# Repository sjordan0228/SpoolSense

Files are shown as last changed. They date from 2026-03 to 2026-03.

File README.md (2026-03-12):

# Voron NFC Spoolman Integration

Automatic filament spool tracking for Voron printers using NFC tags, ESP32-S3, and Spoolman. Built for multi-toolhead setups, works just as well with a single toolhead.


> 🚀 **Big things coming — AFC, OpenPrintTag, and OpenTag3D support**
> SpoolSense is being restructured to support multiple ecosystems. [AFC/Box Turtle](https://github.com/ArmoredTurtle/AFC-Klipper-Add-On) support is actively being built out, with [OpenPrintTag](https://github.com/OpenPrintTag) and [OpenTag3D](https://github.com/OpenTag3D) integrations planned to follow. During this restructuring, some paths and links may temporarily break — if something looks off, check the [CHANGELOG](CHANGELOG.md) or open an issue.

> 🚧 **Work in Progress**
> This project is a work in progress — honestly more of a guide than a finished product. Yes, there's custom code here, but the main idea is to leverage as much open-source software and tooling as possible to build a working system. Check back often because there's a lot planned. Ideas and contributions are very welcome — open an issue or submit a PR!

> 🙋 **Help Wanted**
> - **Case Design** — I'm currently using a basic printed case and would love help designing something slicker. Ideally something that styles well with popular filament dryers — I'm running the Creality Space Pi X4, but open to designs that work across different dryers. If you're a CAD person, let's collaborate!
> - **Testers & Feedback** — If you build this or any variation of it, please open an issue and let me know how it went. Hardware differences, edge cases, things that didn't work — all of it is valuable.

> 🎯 **Stretch Goal — Bondtech INDX Support**
> A top priority stretch goal is to extend this project to support the [Bondtech INDX](https://www.bondtech.se/indx-by-bondtech/) system as soon as it's publicly available. INDX on a Klipper-based printer is a natural fit for this project — the architecture is already there. If you're from the Bondtech team and want to collaborate, feel free to open an issue or reach out via GitHub.

## Overview

Scan an NFC tag on a filament spool → automatically sets the active spool in Spoolman → updates Spoolman per toolhead → Klipper tracks filament usage → LED on each toolhead confirms the scan and displays the spool color.

```
Scan NFC tag
     ↓
ESP32-S3 + PN532 reads UID
     ↓
ESPHome publishes to MQTT
     ↓
Python middleware on Pi
     ↓
Spoolman lookup by UID
     ↓
Moonraker sets active spool
     ↓
Mainsail/Fluidd shows spool per toolhead
     ↓
LED flashes white 3x (scan confirmed) → holds spool color
```

## Features

Tap an NFC tag on your spool and walk away. That's really it — everything else happens automatically.

**Scan to track** — each toolhead has its own ESP32-S3 constantly listening for NFC tags. The moment you tap a spool, it's registered as active in Spoolman, Moonraker is updated, and your front end reflects it per toolhead. No typing spool IDs, no dropdown menus, no forgetting to update it.

**LED feedback that actually tells you something** — the onboard RGB LED isn't just an "it worked" light. It flashes the filament's exact color from Spoolman so you can glance at the toolhead and know what's loaded. Scan an unknown tag and it goes red. Running low (under 100g)? The LED starts breathing in the filament color so it catches your eye without being obnoxious.

**Survives reboots** — spool IDs are saved to disk via Klipper's save_variables system and restored automatically on startup. Pull the power, come back the next day, and everything is still assigned correctly.

**Scales from single to as many toolheads as you need** — originally built for multi-toolhead setups like MadMax, StealthChanger, and other Voron toolchanger systems, but there's nothing stopping you from running a single reader on a standard setup. Each toolhead is completely independent with its own reader and ESP32, but they all feed into the same Spoolman instance. Configure the `TOOLHEADS` list in the middleware to match your setup — `["T0"]` for single, or as many as you're running. Both Fluidd and Mainsail support per-toolhead spool status natively via `variable_spool_id` in the toolchange macros (Mainsail added this in July 2024).

**Single or toolchanger mode** — set `TOOLHEAD_MODE` in the middleware config to match your printer. Single mode calls `SET_ACTIVE_SPOOL` directly on every scan. Toolchanger mode stores the spool ID per toolhead and lets klipper-toolchanger handle activation automatically at each toolchange — tested and confirmed working on MadMax T0–T3.

**Printable case included** — a custom case is in the `3mf/` folder designed specifically for the Waveshare ESP32-S3-Zero + PN532. Print it clear so the LED glows through. Print the scan target in red so you know where to tap.

## LED Status Indicator
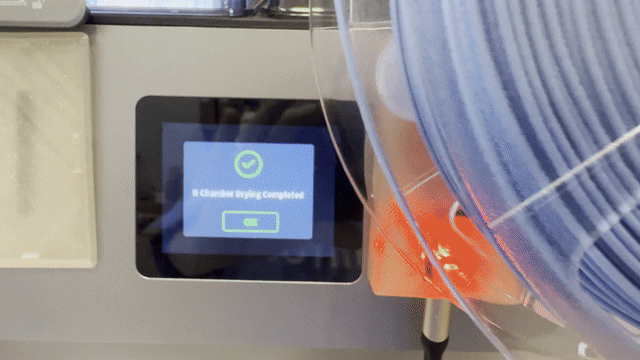
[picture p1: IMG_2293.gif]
LED Status Demo


Each toolhead's onboard WS2812 RGB LED provides visual feedback. This project is tested with the **Waveshare ESP32-S3-Zero**, which includes an onboard WS2812 LED on GPIO21 — no additional wiring required for the LED.

- **3x white flash** — NFC tag successfully scanned
- **Solid spool color** — displays the filament color pulled from Spoolman after a successful scan
- **3x red flash** — tag scanned but not found in Spoolman (unknown or unregistered tag)
- **Breathing in spool color** — spool is running low (at or below `LOW_SPOOL_THRESHOLD`, default 100g)

The LED color is published via MQTT and driven by the middleware using the `color_hex` value stored in Spoolman for each spool.

## Hardware

- 4x [Waveshare ESP32-S3-Zero](https://www.waveshare.com/esp32-s3-zero.htm) *(tested and recommended — onboard WS2812 LED on GPIO21)*
- 4x PN532 NFC Module (I2C mode)
- 4x WS2812 RGB LED (onboard on Waveshare ESP32-S3-Zero, GPIO21)
- Raspberry Pi (Klipper host)
- NFC tags (one per spool)

## Software Stack

- [ESPHome](https://esphome.io) — firmware for ESP32-S3
- [Mosquitto MQTT](https://mosquitto.org) — via Home Assistant addon
- [Spoolman](https://github.com/Donkie/Spoolman) — filament database
- [Moonraker](https://moonraker.readthedocs.io) — Klipper API
- [Fluidd](https://fluidd.xyz) or [Mainsail](https://docs.mainsail.xyz) — both support per-toolhead spool display via `variable_spool_id` in toolchange macros.

## Prerequisites

- Home Assistant with ESPHome and Mosquitto addons
- Klipper + Moonraker running on Raspberry Pi
- Spoolman installed and running
- Fluidd or Mainsail installed

## 3D Printed Case

A custom case is included in the `3mf/` directory, modified from [this model on MakerWorld](https://makerworld.com/en/models/2108947-esp32-c3-pn532-nfc-reader-case-usb-c#profileId-2552448).

Modifications made:
- **Toolhead labels** — T0, T1, T2, T3 text added to each case
- **ESP32-S3-Zero fit** — modified bay designed specifically for the Waveshare ESP32-S3-Zero (get the version without pins and solder wires directly)
- **Scan target** — added a scan target area on the case, suggested to print in red filament

**Printing tips:**
- Print the case itself in a **clear material** (PLA, PETG, or PC) to let the onboard LED shine through for full visual effect
- Print the scan target insert in red for easy identification

## Directory Structure

```
├── esphome/          # ESPHome YAML configs for each toolhead
├── middleware/       # Python MQTT listener script
├── klipper/          # Klipper macro configs
├── 3mf/              # 3D printable case files
├── docs/             # Setup guides
├── scripts/          # Install script (beta)
└── beta/             # Beta features and design docs
```

## Quick Start

**Option A — Interactive install script (beta):**
```bash
git clone https://github.com/sjordan0228/SpoolSense.git
cd SpoolSense
bash scripts/install-beta.sh
```
The script walks you through configuration, installs dependencies, sets up the systemd service, and generates ESPHome YAML files for each scanner.

**Option B — Manual setup:**
1. Wire the PN532 to each ESP32-S3 (see docs/wiring.md)
2. Flash ESPHome configs (see docs/esphome-setup.md)
3. Deploy middleware script (see docs/middleware-setup.md)
4. Add Klipper macros (see docs/klipper-setup.md)
5. Configure Spoolman extra fields (see docs/spoolman-setup.md)

## Automatic Updates via Moonraker

You can add this project to Moonraker's `update_manager` so it appears alongside Klipper, Moonraker, and your other components in Fluidd/Mainsail's update panel. When an update is available, click update and Moonraker will pull the latest code and restart the middleware service automatically.

Add the following to your `moonraker.conf`:

```ini
[update_manager spoolsense]
type: git_repo
path: ~/SpoolSense
origin: https://github.com/sjordan0228/SpoolSense.git
primary_branch: master
managed_services: spoolsense
```

Then clone the repo to your home directory if you haven't already:

```bash
cd ~
git clone https://github.com/sjordan0228/SpoolSense.git
```

Restart Moonraker to pick up the new config:

```bash
sudo systemctl restart moonraker
```

The project should now appear in your update manager panel. Your configuration in `~/SpoolSense/config.yaml` is separate from the repo and will never be overwritten by updates.

## License

GPL-3.0

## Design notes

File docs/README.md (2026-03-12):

# SpoolSense Documentation

> ⚠️ **AFC/BoxTurtle users:** The AFC integration is partially functional — spool scanning and `SET_SPOOL_ID` work today, but LED lane color override depends on [AFC-Klipper-Add-On PR #671](https://github.com/ArmoredTurtle/AFC-Klipper-Add-On/pull/671) being merged before it is fully operational. See [integrations/afc/docs/setup.md](../integrations/afc/docs/setup.md) for the full AFC setup guide.

---

## Toolchanger / Single Toolhead

These guides cover the standard SpoolSense setup — one ESP32-S3-Zero + PN532 per toolhead, or one for a single toolhead printer.

| Guide | What it covers |
|---|---|
| [wiring.md](wiring.md) | PN532 wiring to ESP32-S3-Zero, DIP switch settings |
| [esphome-setup.md](esphome-setup.md) | Flashing ESPHome firmware, adopting into Home Assistant |
| [middleware-setup.md](middleware-setup.md) | Installing and configuring the `spoolsense` middleware service |
| [klipper-setup.md](klipper-setup.md) | Klipper macros, spool ID persistence across reboots |
| [spoolman-setup.md](spoolman-setup.md) | Spoolman extra fields, NFC tag registration, low spool warnings |

---

## AFC / BoxTurtle

AFC-specific docs live in [integrations/afc/docs/](../integrations/afc/docs/).

| Guide | What it covers |
|---|---|
| [setup.md](../integrations/afc/docs/setup.md) | Full AFC setup guide (ESPHome, middleware, Klipper, Spoolman) |
| [wiring.md](../integrations/afc/docs/wiring.md) | PN532 wiring for BoxTurtle (one ESP32-S3-Zero per lane) |

> ⚠️ **AFC LED color override is not yet functional.** It requires [AFC-Klipper-Add-On PR #671](https://github.com/ArmoredTurtle/AFC-Klipper-Add-On/pull/671) to be merged. Spool scanning and `SET_SPOOL_ID` registration work without it — lanes will identify spools correctly, but LED colors will follow AFC's defaults until the PR lands.

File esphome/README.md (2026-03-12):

# ESPHome Configs

This directory contains ESPHome firmware configs for SpoolSense NFC scanners.

---

## Which file do I use?

### Single toolhead or multi-toolhead (toolchanger)

Use `toolhead-t0.yaml` through `toolhead-t3.yaml` — one per physical toolhead.

Each file is a thin wrapper that sets the toolhead's ID and WiFi/IP config, then pulls all shared logic from `base.yaml`. You only need to edit the wrapper file before flashing.

| File | Toolhead ID |
|---|---|
| `toolhead-t0.yaml` | T0 |
| `toolhead-t1.yaml` | T1 |
| `toolhead-t2.yaml` | T2 |
| `toolhead-t3.yaml` | T3 |

For a **single toolhead**, just flash `toolhead-t0.yaml` (or rename `T0` to whatever your setup uses).

For a **custom toolhead name** (e.g. `tool_carriage_0`), duplicate one of the wrapper files and change `toolhead_id` in the substitutions block.

---

### AFC / BoxTurtle (per-lane scanner)

Use `integrations/afc/esphome/lane-pn532.yaml`.

This is a standalone file — flash one copy per lane, changing `lane_id` and the WiFi/IP settings each time. See the [AFC setup guide](../integrations/afc/docs/setup.md) for full instructions.

| Lane | `lane_id` value |
|---|---|
| Lane 1 | `lane1` |
| Lane 2 | `lane2` |
| Lane 3 | `lane3` |
| Lane 4 | `lane4` |

Lane names must match your AFC config (`[AFC_stepper lane1]` etc.).

---

## What to edit before flashing

### Toolchanger wrapper files (`toolhead-t0.yaml` etc.)

```yaml
substitutions:
  toolhead_id: "T0"          # change if needed
  friendly_name: "Toolhead T0 NFC"

wifi:
  manual_ip:
    static_ip: 192.168.X.X   # ← set this
    gateway: 192.168.X.1     # ← set this
  ap:
    password: "CHANGE_ME"    # ← set this
```

### AFC lane file (`lane-pn532.yaml`)

```yaml
substitutions:
  lane_id: "lane1"                      # ← change per lane
  friendly_name: "BoxTurtle Lane 1 NFC" # ← change per lane

wifi:
  manual_ip:
    static_ip: 192.168.X.X   # ← set this (different IP per lane)
    gateway: 192.168.X.1     # ← set this
  ap:
    password: "CHANGE_ME"    # ← set this
```

---

## Secrets file

All configs read WiFi and MQTT credentials from your ESPHome secrets file. In Home Assistant, go to **ESPHome → Secrets** and add:

```yaml
wifi_ssid: "YourNetworkName"
wifi_password: "YourWiFiPassword"
mqtt_broker: "192.168.1.100"    # Your Home Assistant / MQTT broker IP
mqtt_username: "your_username"
mqtt_password: "your_password"
```

---

## How to flash (first time)

1. Go to **https://web.esphome.io** in Chrome or Edge
2. Plug the ESP32-S3-Zero into your PC via USB
3. Click **"Prepare for first use"** → **Connect** → select the serial port
4. After the base flash completes, the ESP32 will broadcast a fallback WiFi hotspot
5. Connect to the hotspot and enter your WiFi credentials
6. Adopt the device in your Home Assistant ESPHome dashboard
7. Click **Edit** on the device, paste in your config file contents, click **Save → Install → Wirelessly**

After the first flash, all future updates are wireless (OTA) directly from the ESPHome dashboard.

---

## Hardware reference

| Component | Toolchanger / Single | AFC per-lane |
|---|---|---|
| Board | ESP32-S3-Zero | ESP32-S3-Zero |
| Scanner | PN532 (I2C) | PN532 (I2C) |
| I2C SDA | GPIO1 | GPIO1 |
| I2C SCL | GPIO2 | GPIO2 |
| Status LED | GPIO21 (WS2812) | not used |
| Lock mechanism | no | yes |

PN532 DIP switch settings for I2C mode: **Switch 1 ON, Switch 2 OFF**.

---

## Directory structure

```
esphome/
├── base.yaml              # Shared logic for toolchanger/single (do not flash directly)
├── toolhead-t0.yaml       # Flash this for T0
├── toolhead-t1.yaml       # Flash this for T1
├── toolhead-t2.yaml       # Flash this for T2
├── toolhead-t3.yaml       # Flash this for T3
└── README.md              # This file

integrations/afc/esphome/
└── lane-pn532.yaml        # Flash this per AFC lane (edit substitutions each time)
```

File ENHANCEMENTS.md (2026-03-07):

# Future Enhancements

Ideas and known improvements for future development. Contributions welcome.

For features actively being designed and prototyped, check the `beta/` folder.

---

## Reliability

**Watchdog timer on ESP32**
If the MQTT connection drops or the NFC reader hangs, the ESP32 currently just sits there. A watchdog timer would auto-restart the device after a set timeout, so it self-recovers without needing a manual power cycle.

**Retry logic in middleware**
If Spoolman or Moonraker is temporarily unreachable (reboot, network blip), the middleware currently just logs an error and moves on. Should implement retry logic with a short backoff so transient failures don't result in a missed scan.

**Debounce NFC reads**
A tag left sitting on the reader will spam repeated scan events continuously. The middleware or ESPHome should debounce this — once a UID has been successfully processed, ignore repeated scans of the same UID for a few seconds before allowing it to trigger again.

---

## Middleware

**Smarter Spoolman lookups**
`find_spool_by_nfc` currently fetches every spool from Spoolman on every scan and loops through them in Python to find a match. Spoolman's API supports filtering — we should query directly by NFC ID instead of pulling the whole list. Not a problem at 10 spools, starts to feel sloppy at 50+.

**MQTT auto-reconnect**
The middleware has no reconnect logic. If the MQTT broker goes down (Home Assistant update, power blip, whatever), the script dies and stays dead until you manually restart it. Needs an `on_disconnect` callback with automatic reconnect so it just heals itself.

~~**Configurable low spool threshold**
The 100g low spool warning is hardcoded. Should be a variable at the top of the config alongside the other settings — people running 250g mini spools have very different needs than someone running 3kg spools.~~ ✅ Done — `LOW_SPOOL_THRESHOLD` added to middleware config.

~~**External config file**
All configuration (MQTT credentials, Spoolman/Moonraker URLs, toolhead mode, toolheads list, low spool threshold) was hardcoded at the top of `nfc_listener.py`. This meant every `git pull` or update could overwrite the user's settings, and made it impossible to use Moonraker's `update_manager` for automatic updates. Config should live in a separate file that's never touched by git.~~ ✅ Done — middleware now loads all settings from `~/nfc_spoolman/config.yaml`. The Python source is safe to overwrite on updates. See `config.example.yaml` for the documented template.

---

## ESPHome

**Fix scan flash vs. MQTT publish order**
Right now the white flash plays out fully before the MQTT publish fires. That means there's a window where the flash is done but the LED hasn't updated to the spool color yet. The publish should fire immediately when the tag is scanned, with the flash happening in parallel while the middleware does its work.

~~**Remove dead lambda in color handler**
There's a leftover no-op lambda at the top of the color MQTT handler that does nothing. Just noise — should be cleaned up.~~ ✅ Done — removed in the base.yaml refactor.

**`on_tag_removed` handling**
The PN532 supports an `on_tag_removed` event that fires when a tag leaves the reader. Right now the LED holds the last color indefinitely after you pull the spool away. Could dim the LED or turn it off when the tag is removed to make it clearer nothing is actively on the reader.

~~**Single shared base config**
All 4 ESPHome YAML files are nearly identical — the only real differences are the toolhead name, static IP, and topic names. Any change to shared logic (like the LED effects we just added) has to be copy-pasted across all 4 files. ESPHome supports `!include` and packages — a single `base.yaml` with all the logic, and each toolhead file just defines its name and IP, would make maintenance much cleaner.~~ ✅ Done — `base.yaml` contains all shared logic, toolhead files are thin wrappers with substitutions. Dead lambda in color handler also removed.

---

## Home Assistant Integration

**Push notifications for low spool and unknown tags**
The middleware already knows when a spool is low or when an unknown tag is scanned — it's just logging it to the console. It could publish to Home Assistant's notification service at the same time so you get a phone alert rather than relying on noticing the LED.

---

## Klipper

~~**`TOOLHEAD_MODE` config variable for single vs. toolchanger setups**
Automatic spool activation via toolchange macros already works correctly for klipper-toolchanger users — tested and confirmed that `SET_ACTIVE_SPOOL` / `CLEAR_ACTIVE_SPOOL` fire on every toolchange and Spoolman tracks filament usage per-spool throughout a multi-toolhead print. No Klipper macro changes needed for toolchanger users. `TOOLHEAD_MODE` config variable added to middleware (`"single"` or `"toolchanger"`). Single mode calls `SET_ACTIVE_SPOOL` directly on scan. Toolchanger mode skips it and lets klipper-toolchanger handle activation at each toolchange.~~ ✅ Done — `TOOLHEAD_MODE` added to middleware in v1.2.2.

## Installation

**Interactive install script**
Right now setup requires manually editing config files, copying files to the right places, and setting up the systemd service — a lot of steps that are easy to get wrong. An interactive install script would walk the user through everything after a `git clone`.

When run, it would prompt for all the values that currently require manual editing:

- Single toolhead or toolchanger mode (`TOOLHEAD_MODE`) — asked first, drives everything else
- Number of toolheads (if toolchanger mode)
- MQTT broker IP, username, and password
- Spoolman IP and port
- Moonraker/Klipper IP
- Low spool threshold

Once the user answers the prompts, the script would write out the configured `nfc_listener.py`, install dependencies, copy the systemd service file, and start the service — all in one shot. At the end it could do a quick connectivity check against the MQTT broker and Spoolman to confirm everything is reachable before exiting.

The goal is: `git clone` → `./install.sh` → answer a few questions → done.

## Quality of Life

**Klipper error alerts via LED**
When something goes wrong mid-print — filament jam, runout, pause — Klipper could publish an MQTT message to the affected toolhead's ESP32 to trigger a visual alert on the LED. ESPHome already subscribes to MQTT topics and knows how to blink LEDs, so this fits naturally into the existing architecture.

Potential alert states:
- Slow red blink — filament jam detected on this toolhead (SFS sensor triggered)
- Fast red blink — more urgent error requiring immediate attention
- Yellow pulse — print paused, waiting for user input
- LED returns to spool color automatically when the issue is cleared and print resumes

Since each toolhead has its own LED, alerts would be per-toolhead — if T2 jams, only T2 blinks red. No need to look at a screen to know which toolhead needs attention.

The main thing to validate is whether Moonraker's built-in MQTT client can publish arbitrary messages directly from a gcode macro, or whether the middleware needs to handle the publishing. The ESPHome and LED side of this should be straightforward given what's already built.

## Future Platform Support

**Bondtech INDX compatibility**
A longer term goal is to get this project working with the Bondtech INDX system once it's publicly available (retail sales expected Q2 2026). INDX supports up to 8 toolheads and is firmware-agnostic — it works with Klipper, Marlin, and RRF — making it a natural fit for this project.

For Klipper-based printers running INDX (Voron, custom builds, etc.) the existing stack should work with minimal changes since the architecture is the same — Klipper, Moonraker, and Spoolman are all still in play. The main things to validate would be toolchange macro compatibility with however INDX implements its tool swaps, and scaling the ESPHome configs and NFC readers beyond 4 toolheads up to 8.

Note: The Prusa CORE One is a high-profile INDX target but runs Prusa's proprietary firmware rather than Klipper, which means Moonraker and Spoolman integration would work completely differently there. The primary focus for this project should be INDX on Klipper-based printers where the existing stack applies directly.

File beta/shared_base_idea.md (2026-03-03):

# Shared Base Config — Design Notes

This is a draft concept for refactoring the 4 ESPHome YAML files into a single shared base config. Not implemented yet — see ENHANCEMENTS.md for context.

## The Problem

All 4 toolhead YAML files (T0–T3) are nearly identical. Any change to shared logic — like the LED effects we recently added — has to be manually applied to all 4 files. This is error-prone and gets worse as the project grows.

## The Solution

ESPHome supports `substitutions` and `packages: !include` which lets us split the config into:

- **`base.yaml`** — all shared logic (LED, MQTT handlers, PN532, I2C). Never edited directly.
- **`toolhead-tX.yaml`** — thin wrapper per toolhead. Only contains the device name, static IP, and a `substitutions` block defining the toolhead ID.

The `${toolhead_id}` substitution variable gets replaced at compile time, so MQTT topics, log messages, and LED names all resolve correctly for each toolhead without any duplicated logic.

## Dependency

This refactor should be done **before** building the install script, since the install script will generate the thin `toolhead-tX.yaml` wrappers automatically based on how many toolheads the user configures.

---

## base.yaml

```yaml
# =============================================================
# NFC Toolchanger Spoolman — Shared Base Config
# =============================================================
# Do not edit this file directly. All toolhead-specific values
# (name, IP, MQTT topics) are set in the individual toolhead files.
# =============================================================

# ESP32-S3 board configuration
esp32:
  variant: esp32s3
  framework:
    type: esp-idf

logger:
api:

ota:
  - platform: esphome

captive_portal:

# I2C bus for PN532
i2c:
  sda: GPIO1
  scl: GPIO2
  frequency: 10000
  scan: true

# Onboard WS2812 RGB LED (GPIO21 on Waveshare ESP32-S3-Zero)
light:
  - platform: esp32_rmt_led_strip
    rgb_order: RGB
    pin: GPIO21
    num_leds: 1
    name: "${friendly_name} Status LED"
    id: status_led
    default_transition_length: 0s
    effects:
      - pulse:
          name: "Low Spool Warning"
          transition_length: 1s
          update_interval: 1s
          min_brightness: 10%
          max_brightness: 80%

# MQTT subscriptions — topics use ${toolhead_id} substitution
mqtt:
  broker: !secret mqtt_broker
  username: !secret mqtt_username
  password: !secret mqtt_password
  on_message:
    - topic: "nfc/toolhead/${toolhead_id}/color"
      then:
        - if:
            condition:
              lambda: 'return x == "error";'
            then:
              # Flash red 3 times — unknown or unregistered tag
              - light.turn_on:
                  id: status_led
                  red: 1.0
                  green: 0.0
                  blue: 0.0
                  brightness: 100%
                  effect: none
              - delay: 200ms
              - light.turn_off:
                  id: status_led
              - delay: 150ms
              - light.turn_on:
                  id: status_led
                  red: 1.0
                  green: 0.0
                  blue: 0.0
                  brightness: 100%
              - delay: 200ms
              - light.turn_off:
                  id: status_led
              - delay: 150ms
              - light.turn_on:
                  id: status_led
                  red: 1.0
                  green: 0.0
                  blue: 0.0
                  brightness: 100%
              - delay: 200ms
              - light.turn_off:
                  id: status_led
            else:
              - lambda: |-
                  std::string hex = x;
                  if (hex.length() == 6) {
                    int r = stoi(hex.substr(0, 2), nullptr, 16);
                    int g = stoi(hex.substr(2, 2), nullptr, 16);
                    int b = stoi(hex.substr(4, 2), nullptr, 16);
                    auto call = id(status_led).turn_on();
                    call.set_effect("none");
                    call.set_rgb(r / 255.0, g / 255.0, b / 255.0);
                    call.perform();
                  } else if (hex == "000000") {
                    id(status_led).turn_off().perform();
                  }
    - topic: "nfc/toolhead/${toolhead_id}/low_spool"
      then:
        - if:
            condition:
              lambda: 'return x == "true";'
            then:
              # Start breathing effect — spool is at or below LOW_SPOOL_THRESHOLD
              - light.turn_on:
                  id: status_led
                  effect: "Low Spool Warning"
            else:
              # Clear breathing effect — restore solid colour
              - light.turn_on:
                  id: status_led
                  effect: none

# PN532 NFC reader
pn532_i2c:
  id: pn532_board
  on_tag:
    then:
      - logger.log:
          format: "Tag scanned on ${toolhead_id}: %s"
          args: [x.c_str()]
      # Flash white 3x on successful scan
      - light.turn_on:
          id: status_led
          red: 1.0
          green: 1.0
          blue: 1.0
          brightness: 100%
      - delay: 150ms
      - light.turn_off:
          id: status_led
      - delay: 100ms
      - light.turn_on:
          id: status_led
          red: 1.0
          green: 1.0
          blue: 1.0
          brightness: 100%
      - delay: 150ms
      - light.turn_off:
          id: status_led
      - delay: 100ms
      - light.turn_on:
          id: status_led
          red: 1.0
          green: 1.0
          blue: 1.0
          brightness: 100%
      - delay: 150ms
      - light.turn_off:
          id: status_led
      - mqtt.publish:
          topic: "nfc/toolhead/${toolhead_id}"
          payload: !lambda |-
            return "{\"uid\": \"" + x + "\", \"toolhead\": \"${toolhead_id}\"}";
```

---

## toolhead-t0.yaml (and T1, T2, T3)

```yaml
# =============================================================
# Toolhead T0 — edit this file for T0-specific settings
# All shared logic lives in base.yaml
# =============================================================

substitutions:
  toolhead_id: "T0"
  friendly_name: "Toolhead T0 NFC"

esphome:
  name: toolhead-t0
  friendly_name: ${friendly_name}
  min_version: 2025.11.0
  name_add_mac_suffix: false

packages:
  base: !include base.yaml

wifi:
  ssid: !secret wifi_ssid
  password: !secret wifi_password
  manual_ip:
    static_ip: 192.168.X.X
    gateway: 192.168.X.1
    subnet: 255.255.255.0
  ap:
    ssid: "Toolhead-T0 Fallback"
    password: "CHANGE_ME"
```

T1, T2, T3 are identical — just change `toolhead_id`, `friendly_name`, `name`, and `static_ip`.

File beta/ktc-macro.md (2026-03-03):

# KTC Macro Changes — Design Notes

> ⚠️ **Everything in this file is assumption and theory at this point. None of this has been tested. Treat it as a starting point for implementation, not a finished solution.**

Design notes for implementing automatic spool activation via klipper-toolchanger (KTC) macros. Suggested by Jim's ID from the #madmax-toolchanger Discord channel.

See ENHANCEMENTS.md (Klipper section) for full context.

---

## The Idea

Currently the T0–T3 macros call `SET_ACTIVE_SPOOL` when a toolchange happens, but only if a `spool_id` is already assigned. The active spool doesn't automatically clear when switching away from a toolhead either — it just stays set until the next toolchange.

The improvement is to make the toolchange sequence explicitly:
1. **Clear** the outgoing toolhead's spool before the change
2. **Activate** the incoming toolhead's spool after the change

This means Spoolman is always tracking the correct spool for whichever toolhead is physically loaded, with no dependency on Fluidd to manage assignments.

---

## What Changes

### spoolman_macros.cfg

No changes needed here — `SET_ACTIVE_SPOOL` and `CLEAR_ACTIVE_SPOOL` already exist and work correctly.

### toolhead_macros_example.cfg

The T0–T3 macros need two small changes:

1. Call `CLEAR_ACTIVE_SPOOL` at the **start** of a toolchange (before `_CHANGE_TOOL`)
2. Call `SET_ACTIVE_SPOOL` at the **end** of a toolchange (after `_CHANGE_TOOL`)

This ensures there's never a window where the wrong spool is being tracked.

---

## What the Updated Macros Look Like

```ini
[gcode_macro T0]
variable_color: ""
variable_tool_number: 0
variable_spool_id: None
gcode:
  # Clear the current spool before switching — stops tracking the outgoing toolhead
  CLEAR_ACTIVE_SPOOL
  # Perform the toolchange
  _CHANGE_TOOL T={tool_number}
  # Activate the incoming toolhead's spool — Spoolman now tracks T0
  {% if spool_id != None %}
    SET_ACTIVE_SPOOL ID={spool_id}
  {% endif %}

[gcode_macro T1]
variable_color: ""
variable_tool_number: 1
variable_spool_id: None
gcode:
  CLEAR_ACTIVE_SPOOL
  _CHANGE_TOOL T={tool_number}
  {% if spool_id != None %}
    SET_ACTIVE_SPOOL ID={spool_id}
  {% endif %}

[gcode_macro T2]
variable_color: ""
variable_tool_number: 2
variable_spool_id: None
gcode:
  CLEAR_ACTIVE_SPOOL
  _CHANGE_TOOL T={tool_number}
  {% if spool_id != None %}
    SET_ACTIVE_SPOOL ID={spool_id}
  {% endif %}

[gcode_macro T3]
variable_color: ""
variable_tool_number: 3
variable_spool_id: None
gcode:
  CLEAR_ACTIVE_SPOOL
  _CHANGE_TOOL T={tool_number}
  {% if spool_id != None %}
    SET_ACTIVE_SPOOL ID={spool_id}
  {% endif %}
```

---

## TOOLHEAD_MODE Awareness

When implementing this, the middleware needs a `TOOLHEAD_MODE` config variable (`"single"` or `"toolchanger"`) so users not running klipper-toolchanger aren't affected. See ENHANCEMENTS.md for details.

The Klipper side should be handled similarly — the `CLEAR_ACTIVE_SPOOL` call at the start of the toolchange macro is harmless for single toolhead users, but the install script should make it clear which parts of the Klipper config are only needed for toolchanger setups.

---

## RESTORE_SPOOL_IDS

No changes needed to the `RESTORE_SPOOL_IDS` delayed_gcode macro — it already restores all toolhead spool IDs from disk on startup, which feeds directly into the updated macros above.

---

## What You Gain

- Spoolman always tracks the correct spool automatically during a print
- No longer dependent on Fluidd to manage spool assignments
- Works with Mainsail, Fluidd, or any other front end
- Single toolhead users are unaffected if `TOOLHEAD_MODE = "single"`

---

## Middleware Changes Required

> ⚠️ Theory — needs testing.

With the KTC macro changes handling `SET_ACTIVE_SPOOL` automatically at toolchange time, the middleware needs to be aware of the mode to avoid redundant or conflicting calls.

**Current middleware behavior on scan:**
1. Look up spool in Spoolman
2. Call `SET_ACTIVE_SPOOL` via Moonraker immediately
3. Save spool ID to disk via `SAVE_VARIABLE`
4. Publish LED color via MQTT

**Problem in toolchanger mode:**
Step 2 becomes redundant. The middleware activates the spool immediately on scan, then the KTC macro clears it and re-activates at the next toolchange anyway. Not broken, but noisy — and could theoretically cause a brief window where the wrong spool is being tracked if a toolchange fires between the scan and the macro running.

**Proposed middleware behavior based on TOOLHEAD_MODE:**

- `TOOLHEAD_MODE = "single"` — no change, keep calling `SET_ACTIVE_SPOOL` on scan as today
- `TOOLHEAD_MODE = "toolchanger"` — skip `SET_ACTIVE_SPOOL` on scan, only save the spool ID to disk and publish the LED color. Let the KTC macro handle activation at toolchange time.

The `SAVE_VARIABLE` call stays in both modes — this is what `RESTORE_SPOOL_IDS` reads on reboot to restore spool assignments after a power cycle.

---

## Print Scenario Walkthrough

> ⚠️ Theory — needs testing.

**Setup:** All 4 spools scanned, spool IDs saved to disk. Print job uses all 4 toolheads.

**What should happen:**

1. Print starts with T0 active → KTC macro fires `SET_ACTIVE_SPOOL` for T0's spool → Spoolman starts tracking filament usage on T0's spool
2. Toolchange to T1 → `CLEAR_ACTIVE_SPOOL` fires first → then `SET_ACTIVE_SPOOL` for T1's spool → Spoolman switches tracking to T1
3. Toolchange to T2 → same pattern → Spoolman tracks T2
4. Toolchange to T3 → same pattern → Spoolman tracks T3
5. Toolchanges back to T0, T1 etc. → continues correctly throughout the print

Filament usage should update correctly at every toolchange since Spoolman is always tracking whichever toolhead is currently active.

**After shutdown:**

Yes — spool assignments survive a shutdown. The middleware saves each toolhead's spool ID to disk via `SAVE_VARIABLE` every time an NFC scan occurs. The `RESTORE_SPOOL_IDS` delayed_gcode macro runs 1 second after Klipper starts and restores all four assignments from disk. You should not need to rescan anything after a reboot or power cut.

**What needs testing:**
- Does `CLEAR_ACTIVE_SPOOL` firing at the start of every toolchange cause any issues with Spoolman's usage tracking mid-print
- Does the timing of `SET_ACTIVE_SPOOL` vs `_CHANGE_TOOL` matter — should activation happen before or after the physical toolchange completes
- Does `RESTORE_SPOOL_IDS` correctly re-activate the last active spool on startup so tracking resumes immediately without needing a scan

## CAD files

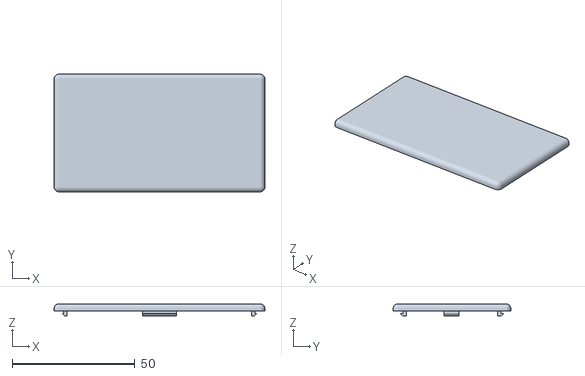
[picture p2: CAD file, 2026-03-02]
3mf/NFC+Reader+Lid+v1.0.stl
86.0 x 48.0 x 5.00

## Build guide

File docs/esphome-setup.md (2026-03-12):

# ESPHome Setup Guide

> **This guide covers toolchanger and single toolhead setups.** AFC/BoxTurtle users: see [integrations/afc/docs/setup.md](../integrations/afc/docs/setup.md) for the AFC setup guide, and `integrations/afc/esphome/lane-pn532.yaml` for the ESPHome config. Note that the AFC integration is not yet fully functional — it depends on [AFC-Klipper-Add-On PR #671](https://github.com/ArmoredTurtle/AFC-Klipper-Add-On/pull/671) being merged.

## Prerequisites

- Home Assistant with ESPHome addon installed
- Mosquitto MQTT broker addon installed and configured in Home Assistant
- Chrome or Edge browser (required for USB flashing)

### Setting up Mosquitto MQTT Broker

If you haven't set up Mosquitto yet, this guide walks you through the full process — installing the addon, creating a user, and connecting it to Home Assistant:

👉 **[Setup MQTT & Mosquitto Broker on Home Assistant — HAProfs](https://haprofs.com/setting-up-mqtt-mosquitto-broker-home-assistant/)**

For a deeper dive into MQTT configuration options, see the official Home Assistant documentation:

👉 **[MQTT Integration — Home Assistant](https://www.home-assistant.io/integrations/mqtt/)**

Once Mosquitto is running and you have a username/password configured, come back here to continue.

## Config Structure

The ESPHome configs use a shared base + thin wrapper approach:

- **`base.yaml`** — all shared logic (LED, NFC, MQTT handlers, I2C). Never edit directly.
- **`toolhead-t0.yaml` through `toolhead-t3.yaml`** — one per toolhead. Only contains the device name, static IP, and substitution variables that identify the toolhead.

Any changes to shared logic (LED effects, MQTT topics, scan behavior) only need to be made in `base.yaml` — all toolheads inherit the changes automatically.

## First Flash (USB Required)

The first flash must be done via USB. After that, all updates are wireless (OTA).

1. Go to **https://web.esphome.io** in Chrome or Edge
2. Click **"Prepare for first use"**
3. Plug ESP32-S3 into your PC via USB
4. Click **Connect** and select **USB JTAG** from the popup
5. Flash the basic firmware
6. Once flashed, connect your PC to the ESP32's fallback hotspot (e.g. `toolhead-t0`)
7. Enter your WiFi credentials in the captive portal at **192.168.4.1**
8. The ESP32 will reboot and connect to your WiFi

## Adopt into Home Assistant ESPHome

1. Go to Home Assistant → ESPHome dashboard
2. The device should appear as **Discovered** — click **Adopt**
3. Or click **Take Control** if it appears in the device list

## Push Full Config

1. In the ESPHome dashboard, click **+ New Device** (or **Edit** if you adopted the device)
2. Replace the config with the contents of the appropriate toolhead YAML (e.g. `toolhead-t0.yaml`)
3. Update the static IP and gateway in the config for your network
4. Upload `base.yaml` to your ESPHome config directory — the toolhead files pull it in via `packages: !include base.yaml`. In the ESPHome dashboard, click the three-dot menu → **Upload file**, then select `esphome/base.yaml` from the repo
5. Update the **Secrets** file in ESPHome with:
   ```yaml
   wifi_ssid: "YourNetworkName"
   wifi_password: "YourWiFiPassword"
   mqtt_broker: "192.168.1.100"
   mqtt_username: "your_ha_username"
   mqtt_password: "your_ha_password"
   ```
   Note: `mqtt_broker` is your Home Assistant / Mosquitto server IP.
6. Click **Save** then **Install → Wirelessly**

## Repeat for T1, T2, T3

Repeat the entire process for each ESP32-S3, using the corresponding toolhead YAML config file. Each toolhead file only differs in its name, toolhead ID, and static IP — all shared logic comes from `base.yaml`.

## Verify

In ESPHome logs you should see:
```
Results from bus scan:
Found i2c device at address 0x24
```

Wave an NFC tag at the reader and you should see:
```
Tag scanned on T0: XX-XX-XX-XX
```

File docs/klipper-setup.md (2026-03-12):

# Klipper Setup Guide

> **This guide covers toolchanger and single toolhead setups.** AFC/BoxTurtle users: see [integrations/afc/docs/setup.md](../integrations/afc/docs/setup.md) for AFC-specific Klipper setup. Note that the AFC LED color integration is not yet functional — it depends on [AFC-Klipper-Add-On PR #671](https://github.com/ArmoredTurtle/AFC-Klipper-Add-On/pull/671) being merged.

## Add Spoolman Macros

Add the following to your `printer.cfg` (or include `spoolman_macros.cfg`):

```ini
[gcode_macro SET_ACTIVE_SPOOL]
description: Set the active spool in Spoolman via Moonraker
gcode:
  {% if params.ID is defined %}
    {action_call_remote_method("spoolman_set_active_spool", spool_id=params.ID|int)}
  {% endif %}

[gcode_macro CLEAR_ACTIVE_SPOOL]
description: Clear the active spool in Spoolman
gcode:
  {action_call_remote_method("spoolman_set_active_spool", spool_id=None)}
```

## Persist Spool IDs Across Reboots

By default, Klipper macro variables reset to `None` when Klipper restarts (e.g. after a power cut or reboot), meaning you'd have to rescan all your spools. To fix this, we use Klipper's `[save_variables]` system to save spool IDs to disk and restore them automatically on startup.

**Step 1 — Add `[save_variables]` to your `printer.cfg`**

You may already have this if you use klipper-toolchanger offset saving or other plugins. You only need one `[save_variables]` block — do not add a second one.

Toolchanger users:
```ini
[save_variables]
filename: ~/printer_data/config/klipper-toolchanger/offset_save_file.cfg
```

Single toolhead users:
```ini
[save_variables]
filename: ~/printer_data/config/variables.cfg
```

**Step 2 — Add the startup restore macro for your mode**

### Single Toolhead Mode

If you're using `spoolman_macros.cfg`, the `RESTORE_SPOOL` macro is already included — it runs 1 second after Klipper starts and re-activates your last scanned spool automatically. No extra setup needed.

If you're defining macros directly in `printer.cfg` instead of using the include file, add this:

```ini
[delayed_gcode RESTORE_SPOOL]
initial_duration: 1
gcode:
  {% set svv = printer.save_variables.variables %}
  {% if svv.t0_spool_id is defined %}
    SET_ACTIVE_SPOOL ID={svv.t0_spool_id}
  {% endif %}
```

### Toolchanger Mode

Add the `RESTORE_SPOOL_IDS` macro from `toolhead_macros_example.cfg`. This restores all toolheads (T0–T3) on startup:

```ini
[delayed_gcode RESTORE_SPOOL_IDS]
initial_duration: 1
gcode:
  {% set svv = printer.save_variables.variables %}
  # Restore T0 spool ID if previously saved
  {% if svv.t0_spool_id is defined %}
    SET_GCODE_VARIABLE MACRO=T0 VARIABLE=spool_id VALUE={svv.t0_spool_id}
    SET_ACTIVE_SPOOL ID={svv.t0_spool_id}
  {% endif %}
  # Restore T1 spool ID if previously saved
  {% if svv.t1_spool_id is defined %}
    SET_GCODE_VARIABLE MACRO=T1 VARIABLE=spool_id VALUE={svv.t1_spool_id}
  {% endif %}
  # Restore T2 spool ID if previously saved
  {% if svv.t2_spool_id is defined %}
    SET_GCODE_VARIABLE MACRO=T2 VARIABLE=spool_id VALUE={svv.t2_spool_id}
  {% endif %}
  # Restore T3 spool ID if previously saved
  {% if svv.t3_spool_id is defined %}
    SET_GCODE_VARIABLE MACRO=T3 VARIABLE=spool_id VALUE={svv.t3_spool_id}
  {% endif %}
```

The middleware automatically saves spool IDs to disk whenever an NFC scan occurs, so the restore macro will always have up-to-date values after a reboot.

## Update Toolhead Macros (Toolchanger Only)

Add `variable_spool_id: None` to each of your T0-T3 toolchange macros so Fluidd or Mainsail can display and assign spools per toolhead.

Example for T0 (replicate for T1, T2, T3):

```ini
[gcode_macro T0]
variable_color: ""
variable_tool_number: 0
variable_spool_id: None
gcode:
  _CHANGE_TOOL T={tool_number}
  {% if spool_id != None %}
    SET_ACTIVE_SPOOL ID={spool_id}
  {% endif %}
```

## Restart Klipper

```bash
sudo systemctl restart klipper
```

## Multi-Toolhead Front End Support

Both Fluidd and Mainsail support per-toolhead spool selection when `variable_spool_id` is present in the toolchange macros. Mainsail added this support in July 2024.

If you prefer Fluidd alongside Mainsail:

1. Download Fluidd:
```bash
mkdir -p ~/fluidd
cd ~/fluidd
wget -q -O fluidd.zip https://github.com/fluidd-core/fluidd/releases/latest/download/fluidd.zip
unzip fluidd.zip
rm fluidd.zip
```

2. Create nginx config at `/etc/nginx/sites-available/fluidd`:
```nginx
server {
    listen 81;
    listen [::]:81;

    root /home/YOUR_USERNAME/fluidd;
    index index.html;

    server_name _;

    location / {
        try_files $uri $uri/ /index.html;
    }

    location /websocket {
        proxy_pass http://apiserver;
        proxy_http_version 1.1;
        proxy_set_header Upgrade $http_upgrade;
        proxy_set_header Connection $connection_upgrade;
        proxy_set_header Host $http_host;
        proxy_set_header X-Real-IP $remote_addr;
    }

    location ~ ^/(printer|api|access|machine|server)/ {
        proxy_pass http://apiserver;
        proxy_http_version 1.1;
        proxy_set_header Host $http_host;
        proxy_set_header X-Real-IP $remote_addr;
    }
}
```

3. Enable and restart nginx:
```bash
sudo ln -s /etc/nginx/sites-available/fluidd /etc/nginx/sites-enabled/fluidd
sudo nginx -t
sudo systemctl restart nginx
```

4. Access Fluidd at `http://YOUR_KLIPPER_IP:81`

5. In Fluidd Settings, add your Spoolman URL under the Spoolman section.

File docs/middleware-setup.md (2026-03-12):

# Middleware Setup Guide

> **This guide covers toolchanger and single toolhead setups.** AFC/BoxTurtle users: the middleware is the same (`spoolsense.py`) but configured with `toolhead_mode: "ams"` — see [integrations/afc/docs/setup.md](../integrations/afc/docs/setup.md) for AFC-specific middleware setup. Note that the AFC integration is not yet fully functional — it depends on [AFC-Klipper-Add-On PR #671](https://github.com/ArmoredTurtle/AFC-Klipper-Add-On/pull/671) being merged.

## Prerequisites

- Raspberry Pi running Klipper/Moonraker
- Python 3 installed
- Spoolman running and accessible

## Installation

1. Clone the repo:
```bash
cd ~
git clone https://github.com/sjordan0228/SpoolSense.git
```

2. Copy the config template and fill in your values:
```bash
cp ~/SpoolSense/middleware/config.example.yaml ~/SpoolSense/config.yaml
nano ~/SpoolSense/config.yaml
```

At minimum you need to set:
- `mqtt.broker` — your Home Assistant / Mosquitto IP
- `mqtt.username` and `mqtt.password` — MQTT credentials
- `spoolman_url` — your Spoolman instance URL
- `moonraker_url` — your Klipper/Moonraker URL

Optional settings have sensible defaults:
- `toolhead_mode` — `"toolchanger"` (default) or `"single"`
- `toolheads` — defaults to `["T0", "T1", "T2", "T3"]`
- `mqtt.port` — defaults to `1883`
- `low_spool_threshold` — defaults to `100` (grams). Controls when the low spool LED warning kicks in. Bump to 200g for an earlier heads-up, or drop to 50g for small 250g spools.

See `config.example.yaml` for full documentation on every option.

3. Install dependencies:
```bash
pip3 install paho-mqtt requests pyyaml --break-system-packages
```

4. Test manually first:
```bash
python3 ~/SpoolSense/middleware/spoolsense.py
```

You should see:
```
Starting NFC Spoolman Middleware (TOOLHEAD_MODE: toolchanger)
Config loaded from /home/youruser/SpoolSense/config.yaml
Toolheads: T0, T1, T2, T3
Connected to MQTT broker (TOOLHEAD_MODE: toolchanger)
Subscribed to nfc/toolhead/ for T0, T1, T2, T3
```

If the config file is missing or has placeholder values, the middleware will exit with a clear error telling you which fields need to be set.

## Install as Systemd Service

1. Copy the service file:
```bash
sudo cp ~/SpoolSense/middleware/spoolsense.service /etc/systemd/system/
```

2. Edit the service file to replace `YOUR_USERNAME` with your actual username:
```bash
sudo nano /etc/systemd/system/spoolsense.service
```

3. Enable and start:
```bash
sudo systemctl enable spoolsense
sudo systemctl start spoolsense
sudo systemctl status spoolsense
```

## Verify

Scan an NFC tag and check the logs:
```bash
journalctl -u spoolsense -f
```

You should see:
```
NFC scan on T0: UID=XX-XX-XX-XX
Found spool: Your Filament Name (ID: 1)
Set spool 1 as active on T0 via Moonraker
```

## Updating Configuration

To change settings after install, edit `~/SpoolSense/config.yaml` and restart the service:
```bash
nano ~/SpoolSense/config.yaml
sudo systemctl restart spoolsense
```

The config file is never touched by `git pull`, so your settings are safe across updates.

## Optional: Automatic Updates via Moonraker

Add the following to your `moonraker.conf`:

```ini
[update_manager spoolsense]
type: git_repo
path: ~/SpoolSense
origin: https://github.com/sjordan0228/SpoolSense.git
primary_branch: master
managed_services: spoolsense
```

Restart Moonraker to pick up the new config:

```bash
sudo systemctl restart moonraker
```

Since the service runs `middleware/spoolsense.py` directly from the repo, updates are seamless — Moonraker pulls the latest code and restarts the service automatically. No manual file copying needed.

Your `~/SpoolSense/config.yaml` is never overwritten — it lives outside the repo.

## Optional: Home Assistant Monitoring

The middleware publishes its online/offline status to `nfc/middleware/online` (retained, QoS 1). If the middleware crashes or loses its MQTT connection, the broker automatically publishes `false` via Last Will and Testament. A clean shutdown also publishes `false` before disconnecting.

If you use Home Assistant, you can optionally surface this as a dashboard sensor. Add the following to your `configuration.yaml`:

```yaml
mqtt:
  binary_sensor:
    - name: "NFC Middleware"
      state_topic: "nfc/middleware/online"
      payload_on: "true"
      payload_off: "false"
      device_class: connectivity
```

This gives you a "Connected / Disconnected" indicator in your HA dashboard and makes it easy to build automations — for example, a notification if the middleware goes offline during a print.

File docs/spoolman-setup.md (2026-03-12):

# Spoolman Setup Guide

> **This guide applies to all setups** (toolchanger, single toolhead, and AFC). The `nfc_id` extra field and NFC tag registration process is the same regardless of mode.

## Add Extra Fields

Spoolman needs two custom extra fields on spools to work with this system.

1. Go to your Spoolman UI (e.g. `http://YOUR_SPOOLMAN_IP:7912`)
2. Go to **Settings → Extra Fields → Spool**
3. Add the following fields:

### Field 1: NFC ID
- **Key:** `nfc_id`
- **Name:** `nfc_id`
- **Field Type:** Text
- **Order:** 1

### Field 2: Active Toolhead
- **Key:** `active_toolhead`
- **Name:** `active_toolhead`
- **Field Type:** Text
- **Order:** 2

## Register NFC Tags on Spools

For each spool:

1. Scan the NFC tag with one of your toolhead readers
2. Check the middleware logs — you'll see:
   ```
   No spool found in Spoolman for UID: XX-XX-XX-XX
   ```
3. Note the UID
4. Go to Spoolman → find or create your spool
5. Edit the spool and enter the UID in the `nfc_id` field

## Low Spool Warning

The LED breathing effect and low spool warning require Spoolman to track filament usage **by weight in grams**. If a spool is only tracking by length (meters), the middleware cannot read `remaining_weight` and the warning will never fire.

To enable weight-based tracking:

1. Go to Spoolman → **Filaments**
2. Find the filament type used by the spool
3. Edit it and set **Spool Weight** — this is the weight of a full new spool in grams (e.g. `1000` for a 1kg spool)
4. Go to Spoolman → **Spools**
5. Edit the spool and set **Used Weight** to reflect how much has been used, or set **Remaining Weight** directly

Once `spool_weight` is set on the filament profile, Spoolman will calculate and return `remaining_weight` in grams. The middleware compares this against `LOW_SPOOL_THRESHOLD` (default: 100g) and triggers the breathing LED effect if the spool is at or below that level.

> **Note:** If your spool is showing remaining length in meters instead of grams in Mainsail or Fluidd, this means `spool_weight` is not set on the filament profile. Set it and the display will switch to grams.

---

## Moonraker Integration

Add the following to your `moonraker.conf`:

```ini
[spoolman]
server: http://YOUR_SPOOLMAN_IP:7912
sync_rate: 5
```

Then restart Moonraker:
```bash
sudo systemctl restart moonraker
```

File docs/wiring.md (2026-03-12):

# Wiring Guide

> **This guide covers toolchanger and single toolhead setups.** AFC/BoxTurtle users: see [integrations/afc/docs/wiring.md](../integrations/afc/docs/wiring.md) for AFC-specific wiring. Note that the AFC integration is not yet fully functional — it depends on [AFC-Klipper-Add-On PR #671](https://github.com/ArmoredTurtle/AFC-Klipper-Add-On/pull/671) being merged.

## PN532 DIP Switch Settings (I2C Mode)

Set the DIP switches on the PN532 board as follows:
- Switch 1: **ON**
- Switch 2: **OFF**

## PN532 to ESP32-S3-Zero Wiring

| PN532 Pin | ESP32-S3-Zero Pin |
|---|---|
| VCC | 3V3 |
| GND | GND |
| SDA | GPIO1 |
| SCL | GPIO2 |

> **Note:** The 3.3V pin on the Waveshare ESP32-S3-Zero is labeled **3V3** on the board. Connect VCC to **3V3**, not 5V — the PN532 operates at 3.3V logic.

### Solder Points on the ESP32-S3-Zero

The photo below shows the exact solder points on the Waveshare ESP32-S3-Zero for connecting a PN532 NFC module. Solder wires directly to the castellated pads — get the version without pre-soldered pins for the cleanest fit inside the printed case.

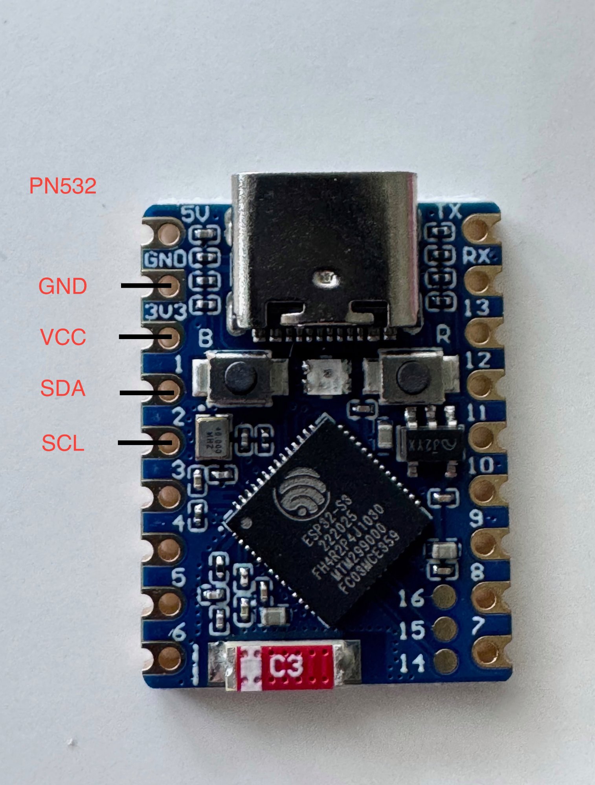
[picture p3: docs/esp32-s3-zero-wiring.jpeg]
ESP32-S3-Zero PN532 Wiring


## I2C Address

The PN532 should appear at address **0x24** on the I2C bus.
You can verify this in the ESPHome logs after flashing — look for:
```
Results from bus scan:
Found i2c device at address 0x24
```

## Onboard LED

The Waveshare ESP32-S3-Zero has a built-in WS2812 RGB LED on **GPIO21**. No additional wiring is needed for the status LED — it's part of the board.

## Notes

- Test with dupont wires before soldering
- One ESP32-S3-Zero + PN532 per toolhead (4 total for a toolchanger setup)
- All units use the same GPIO pins since each is a separate device
- Get the ESP32-S3-Zero version **without pins** and solder wires directly for the best fit in the printed case

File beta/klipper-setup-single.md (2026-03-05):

# Klipper Setup — Single Toolhead

> ⚠️ **Beta doc — not yet linked from main documentation.**

This guide covers Klipper setup for single toolhead printers.

---

## Step 1 — Moonraker Spoolman Integration

Add the following to your `moonraker.conf` if you haven't already:

```ini
[spoolman]
server: http://YOUR_SPOOLMAN_IP:7912
sync_rate: 5
```

Restart Moonraker:
```bash
sudo systemctl restart moonraker
```

---

## Step 2 — Add save_variables to Klipper

Add the following to your `printer.cfg` if you don't already have it:

```ini
[save_variables]
filename: ~/printer_data/config/variables.cfg
```

This is required for the middleware to persist your spool assignment to disk so it survives Klipper restarts and power cuts. You only need one `[save_variables]` block — do not add a second one if you already have it (e.g. from klipper-toolchanger).

---

## Step 3 — Add Spoolman Macros to Klipper

Include `spoolman_macros.cfg` in your `printer.cfg`:

```ini
[include klipper/spoolman_macros.cfg]
```

This defines:
- `SET_ACTIVE_SPOOL` / `CLEAR_ACTIVE_SPOOL` — the macros the middleware uses to tell Spoolman which spool is active
- `RESTORE_SPOOL` — a delayed gcode that runs on startup and re-activates the last scanned spool after a Klipper restart or power cut

Restart Klipper:
```bash
sudo systemctl restart klipper
```

---

## That's it

In single toolhead mode the middleware handles everything automatically on each
NFC scan — no toolchange macros or `variable_spool_id` setup needed.

When you scan a tag:
1. Middleware looks up the spool in Spoolman
2. Calls `SET_ACTIVE_SPOOL` directly via Moonraker
3. Saves the spool ID to disk via `SAVE_VARIABLE`
4. Spoolman starts tracking filament usage against that spool
5. LED updates to the filament colour

After a Klipper restart, the `RESTORE_SPOOL` macro automatically re-activates the last scanned spool — no rescan needed.

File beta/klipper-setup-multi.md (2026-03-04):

# Klipper Setup — Multi-Toolhead (Toolchanger)

> ⚠️ **Beta doc — not yet linked from main documentation.**

This guide covers Klipper setup for multi-toolhead printers running
klipper-toolchanger (e.g. MadMax, StealthChanger).

---

## Step 1 — Moonraker Spoolman Integration

Add the following to your `moonraker.conf` if you haven't already:

```ini
[spoolman]
server: http://YOUR_SPOOLMAN_IP:7912
sync_rate: 5
```

Restart Moonraker:
```bash
sudo systemctl restart moonraker
```

---

## Step 2 — Add Spoolman Macros to Klipper

Include `spoolman_macros.cfg` in your `printer.cfg`:

```ini
[include klipper/spoolman_macros.cfg]
```

This defines `SET_ACTIVE_SPOOL` and `CLEAR_ACTIVE_SPOOL` which your toolchange
macros call at each toolchange.

---

## Step 3 — Update Your Toolchange Macros

Check `klipper/toolhead_macros_example.cfg` for the full example. You need to
add two things to each of your existing T0–TX macros in your
klipper-toolchanger config directory:

**1. Add `variable_spool_id: None`** to the variable block:

```ini
[gcode_macro T0]
variable_color: ""
variable_tool_number: 0
variable_spool_id: None    # ← add this
gcode:
  ...
```

**2. Add the `SET_ACTIVE_SPOOL` call** at the end of the gcode block:

```ini
gcode:
  _CHANGE_TOOL T={tool_number}
  {% if spool_id != None %}    # ← add this
    SET_ACTIVE_SPOOL ID={spool_id}
  {% endif %}
```

Repeat for each toolhead (T1, T2, T3, etc.).

---

## Step 4 — Persist Spool IDs Across Reboots

Add the `RESTORE_SPOOL_IDS` delayed gcode macro so spool assignments survive
a reboot without needing to rescan. See `klipper/toolhead_macros_example.cfg`
for the full macro.

This requires `[save_variables]` in your `printer.cfg` — you likely already
have this if you use klipper-toolchanger's offset saving:

```ini
[save_variables]
filename: ~/printer_data/config/klipper-toolchanger/offset_save_file.cfg
```

---

## Restart Klipper

```bash
sudo systemctl restart klipper
```

---

## How It Works

In toolchanger mode the middleware does NOT call `SET_ACTIVE_SPOOL` directly
on scan. Instead:

1. NFC scan → middleware saves spool ID to Klipper variable and disk
2. Toolchange fires → T0/T1/etc. macro calls `SET_ACTIVE_SPOOL` for the
   incoming toolhead automatically
3. Spoolman switches tracking to the correct spool
4. LED updates to the filament colour

This means Spoolman always tracks whichever toolhead is physically loaded,
with no manual intervention required during a print.

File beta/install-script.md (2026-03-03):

# Install Script — Design Notes

> ⚠️ **Everything in this file is assumption and theory at this point. None of this has been tested. Treat it as a starting point for implementation, not a finished solution.**

Design notes for building an interactive install script to replace the current manual setup process.

See ENHANCEMENTS.md (Installation section) for the original idea summary.

---

## The Problem

Right now setting up this project requires:
- Manually editing config values in `nfc_listener.py`
- Copying files to the right directories on the Pi
- Setting up the systemd service by hand
- Generating ESPHome YAML files per toolhead

That's a lot of steps that are easy to get wrong, especially for someone new to the project.

---

## The Vision

`git clone` → `./install.sh` → answer a few questions → done.

The script handles everything automatically based on the user's answers. No manual file editing required.

---

## Questions the Script Asks

In order:

1. **MQTT broker IP** — Home Assistant server address
2. **MQTT username and password**
3. **Spoolman IP and port** — default 7912
4. **Moonraker/Klipper IP**
5. **Single toolhead or toolchanger mode?** — `single` or `toolchanger`
6. **Number of toolheads** — only asked if toolchanger mode, 1–4
7. **Static IP for each toolhead** — asked once per toolhead (e.g. T0 IP, T1 IP...)
8. **Low spool warning threshold** — default 100g, user can change it

---

## What the Script Does

Once all questions are answered:

**Middleware:**
- Writes configured `nfc_listener.py` with all values substituted
- Installs Python dependencies (`paho-mqtt`, `requests`)
- Copies systemd service file, replacing `YOUR_USERNAME` with the actual user
- Enables and starts the service
- Runs a connectivity check against MQTT broker and Spoolman to confirm everything is reachable

**ESPHome:**
- This is where the dependency on `shared_base_idea.md` comes in — the base config refactor needs to happen first
- Once `base.yaml` exists, the script generates a thin `toolhead-tX.yaml` wrapper for each toolhead the user configured, with the correct `toolhead_id` substitution and static IP filled in
- `base.yaml` is never touched by the install script

**Klipper:**
- If toolchanger mode, reminds the user to add the KTC macro changes (see `ktc-macro.md`)
- If single mode, reminds the user to include `spoolman_macros.cfg` in their `printer.cfg`
- Could potentially copy the right `.cfg` files to the Klipper config directory if the path is known

---

## Dependencies

This script should be built **after**:
1. `shared_base_idea.md` is implemented — the ESPHome base config refactor
2. `TOOLHEAD_MODE` is implemented in the middleware — single vs toolchanger awareness

Without those two pieces in place, the install script can't generate ESPHome configs or configure the middleware correctly for both modes.

---

## End State Confirmation

After the script completes it should print a summary of what was configured and confirm:
- ✅ Middleware service is running
- ✅ MQTT broker reachable
- ✅ Spoolman reachable
- ✅ ESPHome YAML files generated for T0–TX
- Next steps: flash ESPHome configs to each ESP32 (still requires USB first flash)

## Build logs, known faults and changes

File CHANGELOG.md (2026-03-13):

# Changelog

All notable changes to SpoolSense are documented here.

---

## [1.4.0] - 2026-03-12

### Added
- **AFC per-lane ESPHome config** (`integrations/afc/esphome/lane-pn532.yaml`) — standalone ESP32-S3-Zero + PN532 config for BoxTurtle AFC users. Flash one copy per lane, changing `lane_id` and WiFi/IP settings each time. Includes the scan-lock mechanism with a corrected `if:` condition block — the previous config used `return` inside a lambda which did not actually prevent the MQTT publish from firing when a lane was locked.
- **ESPHome directory README** (`esphome/README.md`) — documents which config file to use for each setup, what to edit before flashing, secrets file format, step-by-step first-flash instructions, and a hardware reference table.

---

## [Unreleased] - 2026-03-12

### Added
- **OpenPrintTag and OpenTag3D middleware support (early stages)** — groundwork laid for supporting NFC tags written in the [OpenPrintTag](https://specs.openprinttag.org/) and [OpenTag3D](https://opentag3d.info/spec.html) open standards. This is very early stages — no real scanner, MQTT, or Klipper is involved yet. Development is being done by feeding fake tag payloads directly into the parsers to verify the data pipeline end-to-end before any hardware is wired up.
  - `middleware/state/models.py` — `SpoolInfo` dataclass that normalizes filament data from any tag source into a single common structure (brand, material, color, temps, weights, diameter, lot info, etc.). `SpoolAssignment` dataclass tracks what spool is loaded where (single tool, toolchanger, or AFC lane).
  - `middleware/state/moonraker_db.py` — `MoonrakerDB` class that persists `SpoolInfo` and `SpoolAssignment` objects into Moonraker's key-value database under the `nfc_spoolman` namespace.
  - `middleware/openprinttag/parser.py` — parses decoded OpenPrintTag CBOR payloads into `SpoolInfo`. Handles packed RGBA color conversion to hex and calculates `remaining_weight` from `actual_netto_full_weight - consumed_weight` (remaining weight is not stored directly on the tag).
  - `middleware/opentag3d/parser.py` — parses OpenTag3D Web API JSON payloads into `SpoolInfo`. Field names differ significantly from OpenPrintTag (`manufacturer`, `extruder_temp_min/max`, `spool_weight_nominal`, etc.).
  - `middleware/spoolman/client.py` — `SpoolmanClient` with NFC UID lookup, TTL-based cache (1hr, with forced refresh on miss), tag/Spoolman merge logic (`prefer_tag` flag), weight sync via Spoolman's `used_weight` API field (`used = nominal - remaining`), and NFC UID write-back to Spoolman's `extra.nfc_id` so future scans find the spool without a create attempt.
  - `middleware/config.example.afc.yaml`, `middleware/config.example.single.yaml`, `middleware/config.example.toolchanger.yaml` — split the original `config.example.yaml` into three separate files, one per supported toolhead mode. The original file was renamed to reflect it is AFC-specific.
  - `middleware/test_db.py` — isolated test that saves a fake `SpoolInfo` and `SpoolAssignment` to Moonraker DB to verify the write path (requires a running Moonraker instance).
  - `middleware/test_parsers.py` — fully isolated parser test, no hardware required. Feeds fake tag payloads into both parsers and prints the resulting `SpoolInfo` JSON for inspection.

### Changed
- **Repository restructured for multi-integration support** — the repo is being reorganized to support multiple hardware and firmware ecosystems under a single project. Integration-specific files (ESPHome configs, middleware variants, Klipper macros, docs) are moving into an `integrations/` directory. AFC/Box Turtle support is the first integration landing under this structure (`integrations/afc/`), with [OpenPrintTag](https://github.com/OpenPrintTag) and [OpenTag3D](https://github.com/OpenTag3D) support planned to follow. The core middleware and standard toolchanger/single toolhead setups are not affected. Some paths and doc links may shift during this reorganization — check the README if something looks broken.

---

## [Unreleased] - 2026-03-11

### Added
- **AFC-specific version (Box Turtle)** — a new `afc/` directory contains a variant of SpoolSense for Box Turtle users. This version is not yet functional as it depends on [AFC-Klipper-Add-On PR #671](https://github.com/ArmoredTurtle/AFC-Klipper-Add-On/pull/671), which adds LED lane color support. Once that PR is merged, SpoolSense will be updated to take full advantage of it. Feel free to explore the `afc/` directory in the meantime — a full update will be posted once those changes land.

### Changed
- **Project renamed to SpoolSense** — the repository, middleware script, and service have been renamed from `nfc-toolchanger-spoolman` / `nfc_listener.py` / `nfc-spoolman.service` to `SpoolSense` / `spoolsense.py` / `spoolsense.service`. The install directory is now `~/SpoolSense/`. No functional changes.

---

## [1.3.2] - 2026-03-08

### Fixed
- **ESPHome scan/response race condition** — moved the `mqtt.publish` block to the top of `on_tag` in `base.yaml`, before the white flash animation. Previously the middleware couldn't start its Spoolman lookup until after the ~650ms of white flashes finished, so fast responses from the middleware would collide with the still-running animation and cancel the error/color LED update. Now the UID publishes immediately and the lookup runs in parallel with the flash sequence.
- **Low spool breathing overriding error flash** — when an unknown tag was scanned on a toolhead that previously had a low spool, the `low_spool` topic stayed `true` and the breathing effect would override the red error flash. The middleware now publishes `low_spool: false` on unknown tag scans to clear that state before sending the error color.

### Changed
- **Spoolman spool cache** — middleware now caches all spools locally with a 1-hour TTL instead of querying the Spoolman API on every scan. On cache miss (e.g. newly registered tag), it does a forced refresh. Reduces network overhead for frequent scans.
- **QoS 1 on color and low_spool publishes** — bumped from QoS 0 to QoS 1 to ensure LED state commands are delivered reliably, especially over flaky wifi.
- **Conditional MQTT auth** — `username_pw_set` is now only called when credentials are provided in config, allowing unauthenticated broker setups.

---

## [1.3.1] - 2026-03-07

### Added
- **`RESTORE_SPOOL` macro for single toolhead mode** — `spoolman_macros.cfg` now includes a delayed gcode that re-activates the last scanned spool after a Klipper restart. Previously, single toolhead users lost their active spool assignment on reboot even though the middleware was saving it to disk.
- **Retained MQTT messages for LED persistence** — colour and low spool topics are now published with `retain=True`, so the MQTT broker remembers the last state per toolhead. The ESP32 LED restores to the correct colour automatically after a Klipper restart, ESP32 reboot, or wifi reconnect — no rescan needed.
- **Shared ESPHome base config** — all 4 toolhead YAML files refactored into a single `base.yaml` with shared logic and thin per-toolhead wrappers using ESPHome substitutions. Changes to LED effects, MQTT handlers, or NFC behavior now only need to be made in one place. Dead no-op lambda in the colour handler also removed.
- **Moonraker `update_manager` support** — instructions added to README and middleware-setup.md for automatic updates via Fluidd/Mainsail. The external config file (v1.3.0) makes this possible since `git pull` no longer overwrites user settings.

### Changed
- **ESPHome configs refactored** — `toolhead-t0.yaml` through `toolhead-t3.yaml` are now thin wrappers that include `base.yaml` via `packages: !include`. MQTT broker IP moved from a hardcoded placeholder to `!secret mqtt_broker` — add `mqtt_broker` to your ESPHome secrets file.
- **`SET_GCODE_VARIABLE` gated behind toolchanger mode** — single toolhead printers don't have T0-T3 gcode macros, so the `SET_GCODE_VARIABLE` call now only runs in toolchanger mode. Prevents spurious errors in Moonraker logs for single toolhead users.

---

## [1.3.0] - 2026-03-05

### Added
- **External config file** — all middleware settings now live in `~/SpoolSense/config.yaml` instead of being hardcoded in the Python source. This means `spoolsense.py` is safe to overwrite on updates (`git pull`, Moonraker `update_manager`, etc.) without losing your configuration. The middleware validates the config on startup and exits with clear error messages if required fields are missing or still have placeholder values.
- **`config.example.yaml`** — documented template with all available options and sensible defaults. Copy to `~/SpoolSense/config.yaml` and fill in your values.
- **PyYAML dependency** — `pyyaml` added to required Python packages for config file parsing.
- **Startup config logging** — middleware now logs the loaded config summary (toolhead mode, toolheads, Spoolman/Moonraker URLs, threshold) at startup for easier debugging via `journalctl`.

### Changed
- **Config no longer lives in `spoolsense.py`** — the hardcoded configuration block at the top of the file has been replaced with a `load_config()` function that reads from the external YAML file. Existing users should copy their current values into a new `config.yaml` before updating.
- **`.gitignore`** — `config.yaml` is now ignored so user config is never overwritten by `git pull`.
- **`docs/middleware-setup.md`** — rewritten for the new config file workflow.
- **`scripts/install-beta.sh`** (beta) — updated to write `config.yaml` instead of sed-patching the Python source, and added `pyyaml` to dependency checks.

### Migration from v1.2.x
1. Create your config file: `cp middleware/config.example.yaml ~/SpoolSense/config.yaml`
2. Copy your existing values (MQTT, Spoolman URL, Moonraker URL, etc.) into `config.yaml`
3. Copy the new `spoolsense.py`: `cp middleware/spoolsense.py ~/SpoolSense/`
4. Install pyyaml: `pip3 install pyyaml --break-system-packages`
5. Restart the service: `sudo systemctl restart spoolsense`

---

## [1.2.2] - 2026-03-04

### Added
- **`TOOLHEAD_MODE` config variable** — middleware now supports `"single"` and `"toolchanger"` modes. Single mode works exactly as before — scan a tag, set the active spool, done. Toolchanger mode stores spool IDs per toolhead via `SAVE_VARIABLE` and lets the Klipper toolchange macros handle `SET_ACTIVE_SPOOL` / `CLEAR_ACTIVE_SPOOL` automatically at each toolchange.
- **MQTT Last Will and Testament (LWT)** — broker now automatically publishes `false` to `nfc/middleware/online` if the middleware crashes or loses connection unexpectedly, with QoS 1 and retain so subscribers always have current state
- **Online status publishing** — middleware publishes `true` to `nfc/middleware/online` on successful broker connection. On clean shutdown via SIGTERM or SIGINT, publishes `false` before disconnecting
- **Clean shutdown handler** — `SIGTERM` and `SIGINT` now trigger a graceful shutdown that publishes offline status before disconnecting, so a service restart looks different from a crash to any subscribers

Optionally surface middleware status in Home Assistant — see [middleware-setup.md](docs/middleware-setup.md) for the binary sensor config.

### Changed
- **`TOOLHEADS` config variable** — replaces the hardcoded `["T0", "T1", "T2", "T3"]` list in the subscribe loop. Adjust to match your setup — single toolhead users set `["T0"]`, larger toolchanger setups add entries as needed.

### Confirmed
- **Automatic spool tracking works for toolchanger users** — tested and confirmed that Spoolman correctly tracks filament usage per spool throughout a multi-toolhead print with no Klipper macro changes needed.

### Removed
- `beta/ktc-macro.md` — design doc for KTC macro changes, removed as the behavior it described is already handled natively by klipper-toolchanger

---

## [1.2.1] - 2026-03-03

### Fixed
- **ESPHome 2026.2.x compatibility** — added `chipset: WS2812` to `esp32_rmt_led_strip` config in all 4 toolhead YAML files. ESPHome 2026.2.2 made `chipset` a required field; omitting it caused a compile error: `Must contain exactly one of chipset, bit0_high`

---

## [1.2.0] - 2026-03-02

### Added
- **Configurable low spool threshold** — `LOW_SPOOL_THRESHOLD` variable added to middleware config (default: 100g). Adjust to suit your spool sizes — bump up for an earlier warning, drop down for mini spools.
- **LED error indication** — unknown or unregistered NFC tags now trigger 3x red flashes on the toolhead LED, making scan failures immediately obvious
- **Low spool warning** — when a spool has 100g or less remaining, the LED breathes (pulses between 10%–80% brightness) in the filament's colour to draw attention without losing colour context
- **Low spool MQTT topic** — middleware now publishes `true`/`false` to `nfc/toolhead/Tx/low_spool` after each scan, driven by Spoolman's `remaining_weight` field
- **Pulse effect** added to ESPHome light config (`Low Spool Warning` effect, 1s transition)

### Changed
- Middleware now publishes `"error"` instead of `"000000"` to the colour topic when a tag is not found in Spoolman, allowing ESPHome to distinguish between "no spool" and "error" states

---

## [1.0.0] - 2026-02-28

### Initial Release
- NFC-based filament spool tracking for Voron multi-toolhead printers (T0–T3)
- **Hardware**: Waveshare ESP32-S3-Zero + PN532 NFC module (I2C) per toolhead
- **ESPHome firmware** for all 4 toolheads — reads NFC tag UID and publishes to MQTT
- **Python middleware** (`spoolsense.py`) running on Raspberry Pi — subscribes to MQTT, queries Spoolman by NFC UID, sets active spool in Moonraker, publishes filament colour back to ESP32
- **Klipper macros** for spool tracking and filament usage
- **Spoolman integration** — uses `nfc_id` extra field to map NFC tags to spools
- **LED feedback** — onboard WS2812 RGB LED flashes white 3x on successful scan, then holds the filament's colour from Spoolman
- **Per-toolhead spool display** — supported in both Fluidd and Mainsail via variable_spool_id in toolchange macros
- **MQTT broker** via Home Assistant Mosquitto addon
- **3D printed case** — custom case for Waveshare ESP32-S3-Zero + PN532, modified from MakerWorld model with toolhead labels (T0–T3) and scan target area

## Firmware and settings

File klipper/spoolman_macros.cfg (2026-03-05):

# =============================================================
# Spoolman Klipper Macros
# =============================================================
# These macros allow Klipper to communicate with Spoolman via
# Moonraker's remote method API.
#
# Add these to your printer.cfg, or save this file and include it:
#   [include spoolman_macros.cfg]
#
# Requires Moonraker to have the [spoolman] section configured:
#   [spoolman]
#   server: http://YOUR_SPOOLMAN_IP:7912
#   sync_rate: 5
#
# Single toolhead users: this file includes everything you need —
# SET_ACTIVE_SPOOL, CLEAR_ACTIVE_SPOOL, and a restore macro that
# re-activates your last spool after a Klipper restart.
#
# Toolchanger users: you also need toolhead_macros_example.cfg
# for per-toolhead spool tracking and the multi-tool restore macro.
# =============================================================

# SET_ACTIVE_SPOOL
# Called automatically by toolhead macros (T0-T3) when a toolchange occurs.
# Also called by the NFC middleware via Moonraker's gcode script API.
# Usage: SET_ACTIVE_SPOOL ID=1
[gcode_macro SET_ACTIVE_SPOOL]
description: Set the active spool in Spoolman via Moonraker
gcode:
  {% if params.ID is defined %}
    # Call Moonraker's remote method to update the active spool in Spoolman
    {action_call_remote_method("spoolman_set_active_spool", spool_id=params.ID|int)}
  {% endif %}

# CLEAR_ACTIVE_SPOOL
# Call this at the end of a print to clear the active spool tracking.
# Add to your END_PRINT macro: CLEAR_ACTIVE_SPOOL
[gcode_macro CLEAR_ACTIVE_SPOOL]
description: Clear the active spool in Spoolman
gcode:
  # Pass None to Moonraker to deactivate spool tracking
  {action_call_remote_method("spoolman_set_active_spool", spool_id=None)}

# =============================================================
# Restore Spool After Reboot (Single Toolhead)
# =============================================================
# Runs automatically 1 second after Klipper starts.
# Reads the last saved spool ID from disk and re-activates it
# in Spoolman, so you don't have to rescan after a reboot.
#
# The middleware saves the spool ID via SAVE_VARIABLE every time
# an NFC scan occurs, so this always has the latest value.
#
# Requires [save_variables] in printer.cfg, e.g.:
#   [save_variables]
#   filename: ~/printer_data/config/variables.cfg
#
# Toolchanger users: this macro is NOT needed — use the
# RESTORE_SPOOL_IDS macro in toolhead_macros_example.cfg instead,
# which restores all toolheads (T0–T3).
# =============================================================
[delayed_gcode RESTORE_SPOOL]
initial_duration: 1
gcode:
  {% set svv = printer.save_variables.variables %}
  {% if svv.t0_spool_id is defined %}
    SET_ACTIVE_SPOOL ID={svv.t0_spool_id}
  {% endif %}

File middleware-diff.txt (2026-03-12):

diff -ru middleware/config.example.yaml integrations/afc/middleware/config.example.yaml
--- middleware/config.example.yaml	2026-03-11 22:47:11
+++ integrations/afc/middleware/config.example.yaml	2026-03-12 10:01:25
@@ -5,55 +5,78 @@
 #
 #   cp config.example.yaml ~/SpoolSense/config.yaml
 #
-# The middleware reads ~/SpoolSense/config.yaml on startup.
-# This file (config.example.yaml) is a reference template only.
+# This middleware supports three modes. Set toolhead_mode below.
 # =============================================================
 
-# Toolhead mode — controls how spool activation works
+# ---- Toolhead Mode ------------------------------------------
 #
-#   single      — calls SET_ACTIVE_SPOOL directly on every NFC scan.
-#                 Use this for single-toolhead printers.
+# single      — For single-toolhead printers. Calls SET_ACTIVE_SPOOL
+#               directly on every scan. One ESP32, one PN532.
 #
-#   toolchanger — saves spool ID per toolhead and publishes LED colour,
-#                 but does NOT call SET_ACTIVE_SPOOL. klipper-toolchanger
-#                 handles activation automatically at each toolchange.
-#                 Tested on MadMax T0–T3.
-toolhead_mode: "toolchanger"
+# toolchanger — For multi-toolhead printers (e.g. MadMax, Stealthchanger).
+#               Saves spool ID per toolhead and publishes LED color.
+#               klipper-toolchanger handles SET_ACTIVE_SPOOL at toolchange.
+#
+# ams         — For lane-based filament changers (BoxTurtle, NightOwl, etc.)
+#               running the AFC-Klipper Add-On. Calls AFC's SET_SPOOL_ID
+#               to register the spool in the correct lane. AFC handles
+#               spool tracking, color, material, and weight automatically.
+#
+toolhead_mode: "ams"
 
-# Toolhead identifiers — must match your Klipper tool macro names.
+# ---- Toolheads / Lanes --------------------------------------
 #
-# Single toolhead:
-#   toolheads: ["T0"]
+# For single mode:      ["T0"]
+# For toolchanger mode: ["T0", "T1", "T2", "T3"]
+# For ams mode:         ["lane1", "lane2", "lane3", "lane4"]
 #
-# MadMax / StealthChanger:
-#   toolheads: ["T0", "T1", "T2", "T3"]
+# These must match your MQTT topics and (for ams mode) your AFC
+# lane config names from your AFC_stepper sections.
 #
-# KTC with custom names:
-#   toolheads: ["tool_carriage_0", "tool_carriage_1"]
 toolheads:
-  - "T0"
-  - "T1"
-  - "T2"
-  - "T3"
+  - "lane1"
+  - "lane2"
+  - "lane3"
+  - "lane4"
 
-# MQTT broker — usually your Home Assistant server running Mosquitto
+# ---- MQTT Broker --------------------------------------------
+# Usually your Home Assistant server running Mosquitto.
 mqtt:
   broker: "YOUR_HOME_ASSISTANT_IP"    # e.g. "192.168.1.100"
   port: 1883
   username: "your_mqtt_username"
   password: "your_mqtt_password"
 
-# Spoolman instance URL (default port is 7912)
+# ---- Spoolman URL -------------------------------------------
+# Default port is 7912.
 spoolman_url: "http://YOUR_SPOOLMAN_IP:7912"
 
-# Moonraker / Klipper instance URL
+# ---- Moonraker URL ------------------------------------------
+# Your Klipper/Moonraker instance.
 moonraker_url: "http://YOUR_KLIPPER_IP"
 
-# Low spool warning threshold in grams.
-# When remaining filament drops to this level or below, the LED
-# will pulse to indicate the spool is running low.
-# Adjust based on your spool sizes:
-#   50  — mini/sample spools (250g)
-#   100 — standard 1kg spools (default)
-#   200 — early warning for large prints
+# ---- Low Spool Threshold ------------------------------------
+# Remaining weight (grams) that triggers a low spool warning.
+#
+# single/toolchanger: publishes low_spool status to MQTT and
+#   triggers the ESP32 LED pulse effect.
+# ams: logged to journal only — AFC manages its own low spool
+#   behavior via enable_assist_weight.
+#
 low_spool_threshold: 100
+
+# ---- AMS Mode Options (ignored in single/toolchanger) -------
+
+# Path to AFC's variable file. The middleware watches this file for
+# lane changes (spool insert/eject) to auto-lock/clear scanners and
+# update BoxTurtle LEDs with filament colors.
+afc_var_path: "~/printer_data/config/AFC/AFC.var.unit"
+
+# Path to Klipper's save_variables file (single/toolchanger only).
+# If not set, the middleware auto-discovers it from Moonraker.
+# klipper_var_path: "~/printer_data/config/klipper-toolchanger/offset_save_file.cfg"
+
+# Klipper macro name for setting BoxTurtle lane LED colors.
+# The middleware calls this with: LANE=<name> R=<0-1> G=<0-1> B=<0-1> BREATH=<0|1>
+# You must define this macro in your Klipper config — see afc/docs/setup.md.
+ams_led_macro: "_SET_LANE_LED"
diff -ru middleware/spoolsense.py integrations/afc/middleware/spoolsense.py
--- middleware/spoolsense.py	2026-03-11 22:47:11
+++ integrations/afc/middleware/spoolsense.py	2026-03-12 10:01:25
@@ -1,10 +1,40 @@
 #!/usr/bin/env python3
 """
-NFC Spoolman Middleware
-================================================
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

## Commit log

2026-03-02 Add files via upload
    Lid for the case.
    [NFC+Reader+Lid+v1.0.stl]
2026-03-02 Add 3D printed case documentation, remove Info.md
2026-03-03 Add TOOLHEAD_MODE implementation note to Klipper enhancement
2026-03-03 Add theory warning, middleware changes, and print scenario to ktc-macro.md
2026-03-03 Add Quality of Life section with Klipper error alert via LED idea
2026-03-03 Correct Mainsail/Fluidd per-toolhead spool support across all files (Mainsail added July 2024)
    [toolhead_macros_example.cfg]
2026-03-03 Fix Help Wanted case design description
2026-03-04 Fix ESPHome 2026.2.x compatibility - add chipset: WS2812 to all toolhead configs
    ESPHome 2026.2.2 requires chipset to be explicitly set on esp32_rmt_led_strip.
    Updated all 4 toolhead YAML files and bumped to v1.2.1.
2026-03-04 Trim Klipper toolchange macro enhancement - remove backstory, keep implementation detail
2026-03-04 Replace hardcoded toolhead list with TOOLHEADS config variable
    - Remove MQTT_TOPIC wildcard subscription in favour of per-toolhead subscribes
    - Add TOOLHEADS config variable with example in comment
    - on_connect loop and log message now driven by TOOLHEADS
    - Applied to both middleware/nfc_listener.py and beta/nfc_listener_cache.py
2026-03-04 Update changelog for v1.2.3 - TOOLHEADS config variable
2026-03-04 Clarify TOOLHEADS comment - mention MadMax and KTC custom names
2026-03-04 Add ESPHome YAML generation to install script
    - generate_esphome_yaml() substitutes all toolhead-specific values
    from t0 template: name, friendly_name, MQTT broker, topic names,
    LED label, log message, WiFi AP name, JSON payload toolhead field
    - Generates one file per toolhead into esphome/generated/
    - Warns user to flash via web.esphome.io after generation
    - Summary block lists generated files
    - Add esphome/generated/ to .gitignore (generated, not committed)
    - TODO comment noting future shared base config approach
2026-03-04 install-beta.sh: add TOOLHEAD_MODE support
    - Toolhead mode question moved to first in the flow
    - Single -> TOOLHEAD_MODE=single, Toolchanger/Custom -> TOOLHEAD_MODE=toolchanger
    - write_listener() now accepts and seds in TOOLHEAD_MODE
    - Review summary shows TOOLHEAD_MODE before other config values
    - Renamed 'KTC' option to 'Toolchanger' for clarity
2026-03-04 install-beta.sh: dependency check + friendlier Klipper message
    - Check if paho-mqtt and requests are already installed before running pip
    - Only installs what is actually missing, skips if both present
    - Klipper done screen reworded to direct user to toolhead_macros_example.cfg
    for toolchanger mode, cleaner include instruction for single mode
2026-03-04 Fix single mode done screen + add beta klipper setup docs
    - install-beta.sh: single mode done screen no longer mentions
    toolhead_macros_example.cfg or variable_spool_id — only spoolman_macros.cfg
    - beta/klipper-setup-single.md: new doc for single toolhead Klipper setup
    - beta/klipper-setup-multi.md: new doc for toolchanger Klipper setup
    Both are beta only — not linked from main docs yet
2026-03-05 Rename v1.3.0 to v1.2.2 — no minor version bump warranted
2026-03-05 README: update for current feature set
    - Features: TOOLHEAD_MODE single/toolchanger explained, TOOLHEADS list
    described as flexible (not hardcoded to 4), confirmed working on MadMax
    - LED status: added red flash (unknown tag) and breathing (low spool) states
    - Quick Start: Option A (install script beta) + Option B (manual) structure
    - Directory structure: added scripts/ and beta/ entries
2026-03-05 docs: add low spool warning requirements to spoolman-setup.md
    - Explains that weight-based tracking must be configured in Spoolman
    - Steps to set spool_weight on filament profile and used_weight on spool
    - Notes that meters display in Mainsail means spool_weight is not set
2026-03-05 Add RESTORE_SPOOL macro for single toolhead mode
    Single toolhead users lost their active spool assignment on Klipper
    restart even though the middleware was saving it to disk. Added a
    delayed gcode to spoolman_macros.cfg that re-activates the last
    scanned spool on startup.
    Updated klipper-setup.md to cover both single and toolchanger restore
    workflows side by side.
    [spoolman_macros.cfg]
2026-03-05 Retain MQTT color and low_spool messages for LED persistence
    LED color and low spool breathing effect now survive Klipper restarts,
    ESP32 reconnects, and wifi drops. The MQTT broker holds the last
    published value per toolhead so the ESP32 gets the correct state
    immediately on reconnect without needing a rescan.
2026-03-07 Refactor ESPHome configs into shared base.yaml + thin toolhead wrappers
    All shared logic (LED, NFC, MQTT handlers, I2C, globals) now lives in
    base.yaml. Each toolhead file is a thin wrapper defining only its name,
    static IP, and substitution variables (toolhead_id, friendly_name).
    Changes to LED effects, MQTT topics, or scan behavior now only need
    to be made in one place instead of four.
    Also removed the dead no-op lambda in the MQTT color handler and moved
    the MQTT broker from a hardcoded placeholder to !secret mqtt_broker.
2026-03-07 docs: add ESP32-S3-Zero wiring photo with solder point annotations
    Photo shows exact solder points for PN532 connection (GND, VCC/3U3,
    SDA/GPIO1, SCL/GPIO2). Updated wiring.md with image reference,
    onboard LED note, and improved pin labeling.
2026-03-07 docs: fix 3U3 → 3V3 pin label in wiring guide
2026-03-08 afc: unified middleware supporting single, toolchanger, and ams modes
    Merged all three toolhead_mode handlers into afc/middleware/nfc_listener.py:
    - single: SET_ACTIVE_SPOOL + SAVE_VARIABLE (no SET_GCODE_VARIABLE)
    - toolchanger: SET_GCODE_VARIABLE + SAVE_VARIABLE (klipper-toolchanger activates)
    - ams: SET_SPOOL_ID via AFC + scan lock/clear lifecycle
    Each mode has its own activate_spool_* function, routed by a single
    activate_spool() dispatcher. Mode-specific behavior in on_message:
    - single/toolchanger: publish LED color, low_spool MQTT status, error flash
    - ams: lock scanner after registration, log-only low spool warning
    Updated config.example.yaml to document all three modes with example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
2026-03-12 Updating documentation in esphome and integrating afc changes. Had to make some minor changes
    [middleware-diff.txt]
2026-03-12 Better Comments added to spoolsense.py. Used CoPilot to help me fast track it a bit
